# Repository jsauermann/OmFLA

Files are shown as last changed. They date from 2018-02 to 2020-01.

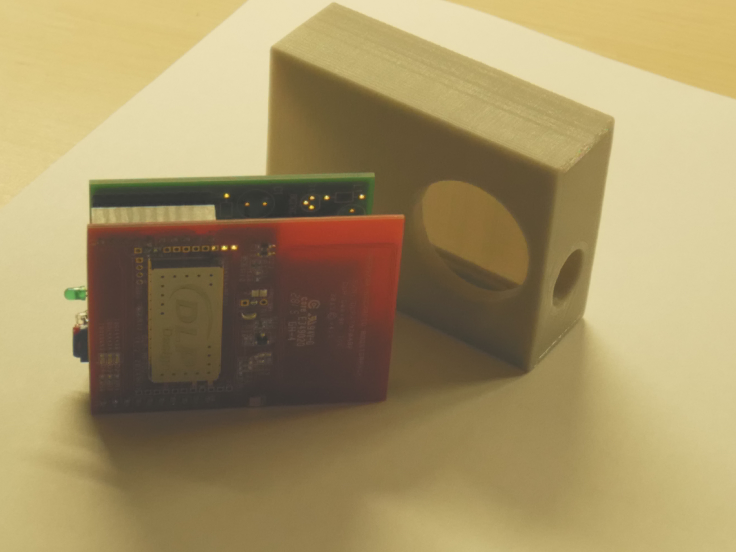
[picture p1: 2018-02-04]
pictures/components.jpg

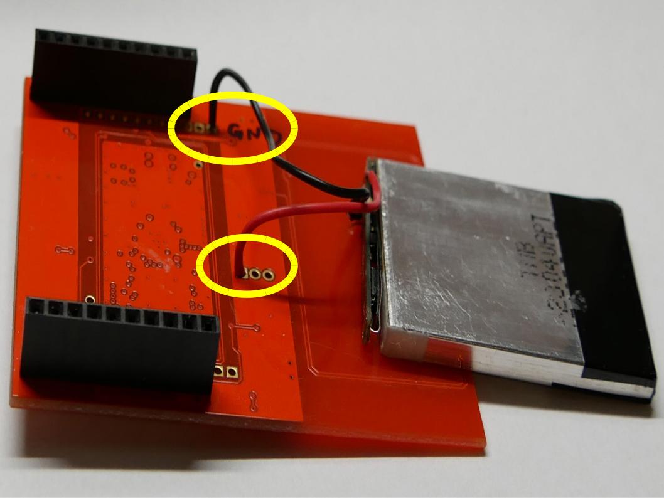
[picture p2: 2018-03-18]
hardware/battery_connected.jpg

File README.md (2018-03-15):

# OmFLA
**O**ne **m**ore **F**reestyle **L**ibre **A**larm

This project contains the hardware (schematic and PCB layout), micro-controller
software (C++ for an Atmel ATtiny 4313), and mechanics (openscad file for 3D
printers) of a small device that MAY be useful for users of Freestyle Libre
glucose sensors. The device beeps if the glucose levels reported by the
sensors exceed certain thresholds.

The device is only reading the sensors and can therefore co-exist with the
standard reader shipped by Abbott. As a consequence the device cannot
initialize new sensors. The primary purpose of the device is to be worn at
night and to warn the user about excessive glucose levels. The purpose is
NOT to replace the standard Abbott reader. In fact, the first action after
an alarm shall be to determine the glucose level with either the standard
reader, or even with a traditional blood glucose measurement.

The PCB of the device is prepared for an Enocean TCM 310 module that can
transmit the glucose levels and the battery level to a receiver withing,
say, 20 meters. Low-cost receiver modules, for example for Raspberry Pis
are available. Alternatively, one can used a second OmFLA PCB as receiver
and connect it to the serial port of a Raspberry Pi or of some
micro-controller.

**DISCLAIMER: This device is not a medical device and does not follow
any established standards for medical devices. It is a purely experimental
device and only meant to demonstrate technical possibilities.**

**The information in this project is distributed in the hope that it will be
useful, but WITHOUT ANY WARRANTY; without even the implied warranty of
MERCHANTABILITY or FITNESS FOR A PARTICULAR PURPOSE.**

A distinguishing feature of the device described in this project is that
it works without any additional devices like expensive smart watches or even
smart-phones. One of the design goals was low cost as opposed to high
functionality, and the cost of the components for the prototype were well
below US-$ 50.00 (including the RFID reader, but excluding the PCB and the
optional TCM 310 radio transceiver).

We are offering OmFLA PCBs to diabetes self aid groups and to individuals suffering
from diabetes at roughly our purchase price + shipping, please send an email to
**omfla@jürgen-sauermann.de** for details.

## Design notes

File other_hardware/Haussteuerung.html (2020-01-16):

Table of Contents

## Jürgen’s Raspberry Pi Zero hat

### Overview

Unlike other Raspberry hats, this hat is larger than the Raspberry Zero, so the raspberry is plugged onto the hat rather than the hat being plugged onto the rapberry.

Although the hat was designed for the Raspberry Pi Zero form factor, it supposedly also works for other Raspberry Pi models.

The hat contains only a few active components; the rest is connectors for various purposes. Almost all components are optional and only needed if the interface that they belong to is needed. The hat provides the following connectors/interfaces:

- J1: The main interface between the hat and the Raspberry Pi Zero
- X1: an interface to a 3 Line LCD Display
- J2: an interface for enocean TCM310 hat (or alternatively a serial interface at 3.3 Volt level (!))
- J3, J4, J5 and J6: I²C interfaces (on the same I²C bus)
- J11/J12 open-collector outputs connected to the Raspi’s hardware PWM units
- J9 and J10: two 220Volt Relays
- SW1: one pushbutton
- J8: 20 pin header with some more general purpose interface lines

All these interfaces are controlled via GPIO lines of the Raspberry; the I²C and PWM interfaces can be realized either in software or in hardware.

### The main connector J1

The only non-optional component is J1, which connects the hat with a Raspberry Pi Zero. The hat gets its power (3.3 and 5 Volts) via its J1 from the Raspberry, therefore the power from the power supply should go into the Raspberry’s normal power connector (J1/PWR IN), and not to the hat’s J1.

Most of the remaining lines on J1 are GPIO lines. Unfortunately there exist exist 2 different naming/numbering conventions: the Broadcom scheme and the WiringPi scheme. If you control the GIPO pins by reading from and writing to files below /sys/class/gpio then the GPIO numbers used are those defined by the Broadcom scheme. If you instead use a library like wiringPi, then the pin numbers are completely differen and are defined by the WiringPi scheme. The following table shows the mapping between the pin numbers of the hat’s J1 connector, the Broadcom scheme, and the WiringPi scheme:

Alias | Wiring Pi Name | Broadcom Name | J1 Pin | | Broadcom Name | Wiring Pi Name | Alias
Power 3.3 Volts | | | 1 | 2 | Power 5 Volts
I²C Data | GPIO-8 | GPIO-2 | 3 | 4
I²C Clock | GPIO-9 | GPIO-3 | 5 | 6 | GND
| GPIO-7 | GPIO-4 | 7 | 8 | GPIO-14 | GPIO-15
GND | | | 9 | 10 | GPIO-15 | GPIO-16
| GPIO-0 | GPIO-17 | 11 | 12 | GPIO-18 | GPIO-1
| GPIO-2 | GPIO-27 | 13 | 14 | GND
| GPIO-3 | GPIO-22 | 15 | 16 | GPIO-23 | GPIO-4
Power | | | 17 | 18 | GPIO-24 | GPIO-5
| GPIO-12 | GPIO-10 | 19 | 20 | GND
| GPIO-13 | GPIO-9 | 21 | 22 | GPIO-25 | GPIO-6
| GPIO-14 | GPIO-11 | 23 | 24 | GPIO-8 | GPIO-10
GND | | | 25 | 26 | GPIO-7 | GPIO-11
| GPIO-30 | | 27 | 28 | GPIO-1 | GPIO-31
| GPIO-21 | GPIO-5 | 29 | 30 | GND
| GPIO-22 | GPIO-6 | 31 | 32 | GPIO-12 | GPIO-26 | PWM-0
PWM-1 | GPIO-23 | GPIO-13 | 33 | 34 | GND
| GPIO-24 | GPIO-19 | 35 | 36 | GPIO-16 | GPIO-27
| GPIO-25 | GPIO-26 | 37 | 38 | GPIO-20 | GPIO-28
GND | | | 39 | 40 | GPIO-21 | GPIO-29

### Enocean connector J2

J2 connects the hat with an Enocean TCM310 based Raspi Transceiver Module. The enocean Module is plugged directly onto J2 of the hat. The connection uses the RxD and TxD lines of RasPi UART (aka. /dev/ttyAMA0). The Data format is 57600 Baud, 8N1. Instead of the TCM310 Module, you can use this connector for other purposes that need a serial connection.

The Enocean connector J2 has the following pinout:

Alias | J2 Pin | | Broadcom Name | Wiring Pi Name | Alias
Power 3.3 Volts | 1 | 2 | -
- | 3 | 4 | -
- | 5 | 6 | GND
- | 7 | 8 | GPIO-14 | GPIO-15 | RxD
- | 9 | 10 | GPIO-15 | GPIO-16 | TxD
- | 11 | 12 | -
- | 13 | 14 | -
- | 15 | 16 | -
- | 17 | 18 | -
- | 19 | 20 | -
- | 21 | 22 | -
- | 23 | 24 | -
- | 25 | 26 | -

### I²C connectors J3, J4, J5, and J6

These connectors are connected in parallel (so that they belong to the same I²C bus). They are typically used to connect sensors. It is normally better to put sensors that are located close to each other on one cable (bus connection) than using separate cables (star connection), because that way the signal reflections at the ends of (unterminated) cables are being reduced.

If the cable(s) are too long then the I²C becomes unreliable and buffering and/or proper termination of the cables might be needed. Another solution for long cables could be to run the I²C in software (using /sys/class/gpio/gpio9/value for the I²C clock and /sys/class/gpio/gpio8/value for the I²C data, instead of /dev/i2c-1.

Every I²C connector J3, J4, J5, or J6 has the same pinout:

Pin | Broadcom Name | WiringPi Name | Alias
1 | Power 3.3 Volts
2 | GPIO-2 | GPIO-8 | I²C Data
3 | GND
4 | GPIO-3 | GPIO-9 | I²C Clock

### LCD Display X1

The hat may optionally be equipped with a 3-line LCD Dispay. The display is mounted on connector X1, which is a standard 40-pin, 600 mil socket with some pins not used. The pinout of X1 is:

Alias | Wiring Pi Name | Broadcom Name | J1 Pin | | Broadcom Name | Wiring Pi Name | Alias
A1 + | J7 Pin 2 3.3/5 Volts | | 1 | 40 | GPIO-11 | GPIO-14 | RESET
C1 - | RLED | | 2 | 39 | GPIO-21 | GPIO-29 | RS
- | | | - | 38 | GND | | CSB
- | | | - | 37 | GPIO-20 | GPIO-28 | R/W
- | | | - | 36 | GPIO-16 | GPIO-27 | E
- | | | - | 35 | | 3.3 Volts | D0
- | | | - | 34 | | | D1
- | | | - | 33 | | | D2
- | | | - | 32 | | | D3
- | | | - | 31 | GPIO-7 | GPIO-11 | D4
- | | | - | 30 | GPIO-8 | GPIO-10 | D5
- | | | - | 29 | GPIO-25 | GPIO-6 | D6
- | | | - | 28 | GPIO-24 | GPIO-5 | D7
- | | | - | 27 | GND | | VSS
- | | | - | 26 | 3.3 Volts | | VDD
- | | | - | 25 | 3.3 Volts | | Vin
- | | | - | 24 | (charge pump) | | Vout
- | | | - | 23 | 3.3 Volts | | PSB
C2 - | GND | | 19 | 22 | (charge pump) | | CAP1P
A2 + | RLED | | 20 | 21 | (charge pump) | | CAP1N

### Backlight Power Selector J7

The optional LCD display X1 can by equipped with an optional LED backlight in order to improve its readability. The optional LED backlight can either be driven from 3.3 Volts or from 5 Volts. Driving it from 5 Volts is supposedly better since the current of the backlight (about 40 mA) does not flow through the RasPi’s 5Volt → 3.3Volt converter.

Jumper J7
1-2 | Run LED backlight from 3.3 Volts
2-3 | Run LED backlight from 5 Volts

Caution | The LED backlight current MUST be limited, this is accomplished by resistor below the LCD display X1. The PCB shows a value of 10 (Ohms). This value is, however, dependant on two factors: the setting of J7 and the color of the LEDs. Typical values lie between about 0 and 30 Ohms, if unsure start with 30 Ohms and decrease as needed. For prototyping use a connector instead of soldering a (possibly incorrect) resistor.

### Extension connector J8

Most of the GPIO lines that are not connected with specific interfaces are conncted to J8. That way additional components can be connected to the RasPi as needed. The Pinout of J8 is:

Wiring Pi Name | Broadcom Name | J8 Pins | | Broadcom Name | Wiring Pi Name
GPIO-13 | GPIO-9 | 1 | 2 | GPIO-10 | GPIO-12
GPIO-5 | GPIO-21 | 3 | 4 | GPIO-3 | GPIO-22
GPIO-6 | GPIO-22 | 5 | 6 | GPIO-4 | GPIO-23
GPIO-19 | GPIO-24 | 7 | 8 | Power 3.3V
GND | | 9 | 10 | GPIO-25 | GPIO-26

### 220 Volt Connectors J9 and J10

The hat can be equipped with one or two relays that both can switch a 220 Volt power line. The Line (L) inputs of J9 and J10 are connected, it is therefore NOT possible to switch different phases, e.g. L1 and L2, of the same neutral (N) line.

The coils of each relays also operate at 220 Volt (or whatever voltage you choose for the relay components) and are galvanically isolated from the hat and the RasPi by means of optocoupler triacs (MOC 3041 or similar). The relay coild both use the primary AC input, therefore the secondary relay cannot be used without the primary.

Note | For operation at 110 Volts you may need smaller values for the 470 Ohm resistors above the LCD display X1. Refer to the MOC 3063 data sheet for details. The coils of the relays should be protected with varistors R7 resp. R8 that suppress inductive spikes when a coil is being turned off. The values of the varistors need to match the voltage used for the relay, e.g. 270 Volts for 220 Volt relay coils and 140 Volts for 110 Volt relay coils.

Warning | Unlike the coils of the relays, the relay contacts are NOT protected with varistors. For ohmic loads (e.g lamps) such protection is not needed, but for inductive loads (e.g. motors for blinds, door openers, etc.) additional protection for the relay contacts is recommended.

Connector J9, the primary 220 Volt connector, has one more pin than J10: this pin provides the neutral (N) line for both relay coils and contacts. The pinouts of J9 and J10 are:

J9 Pin | Purpose
1 | Line out if Relay-1 is ON
2 | Neutral (N)
3 | Line in (L)

J10 Pin | Purpose
1 | Line out if Relay-2 is OFF
2 | Line out if Relay-1 is OFF
3 | Line out if Relay-2 is ON

The relays (ON/OFF) are controlled with the following GPIO pins:

Broadcom Name | Wiring Pi Name | Relay
GPIO-17 | GPIO-0 | Relay-1 ON/OFF
GPIO-27 | GPIO-2 | Relay-2 ON/OFF

### PWM Connectors J11 and J12

J11 provides two PWM channels that are driven by the open collectors of the two transistors next to J1. These signals can be used, for example, to control the speed of fans. J11 has the following pinout:

J10 Pin | Broadcom Name | Wiring Pi Name | Alias
1 | GPIO-12 | GPIO-26 | PWM-1
2 | -
3 | GPIO-23 | GPIO-13 | PWM-0
4 | -
5 | GND

J11 is intended for the case where both PWM channels are routed over the same cable. In contrast, J12 is intended for the case where differen cables are used for the two PWM channels. J12 has the following pinout:

J10 Pin | Broadcom Name | Wiring Pi Name | Alias
1 | -
2 | -
3 | GPIO-12 | GPIO-26 | PWM-1
4 | -
5 | GND

If J12 is used, then typically pin 1 of J11 is not.

Last updated 2020-01-16 21:53:17 CET

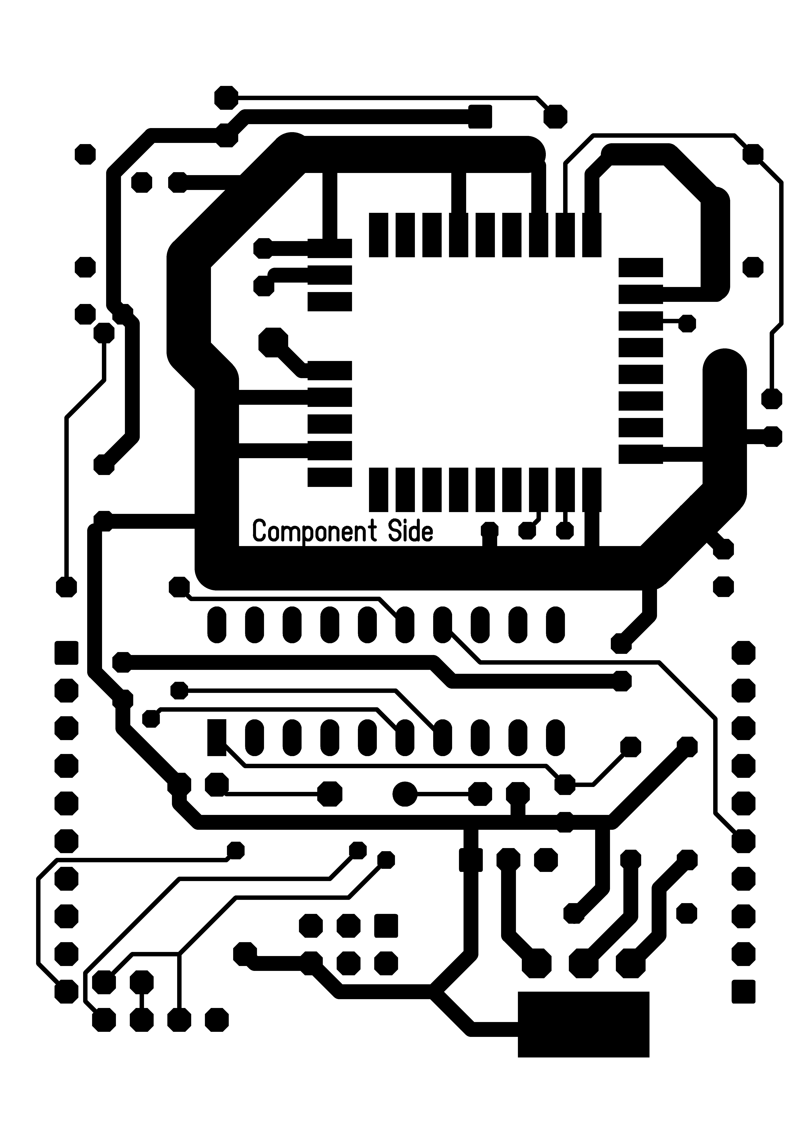
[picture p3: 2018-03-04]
hardware/Top.jpg

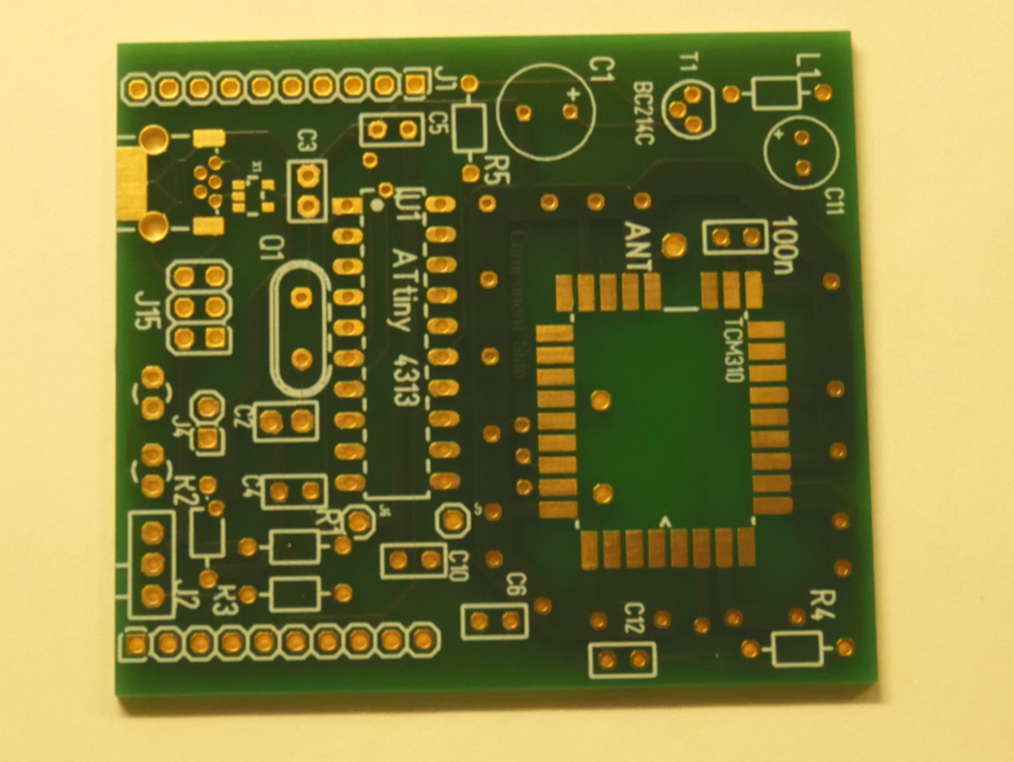
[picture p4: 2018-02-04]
hardware/PCB.jpg

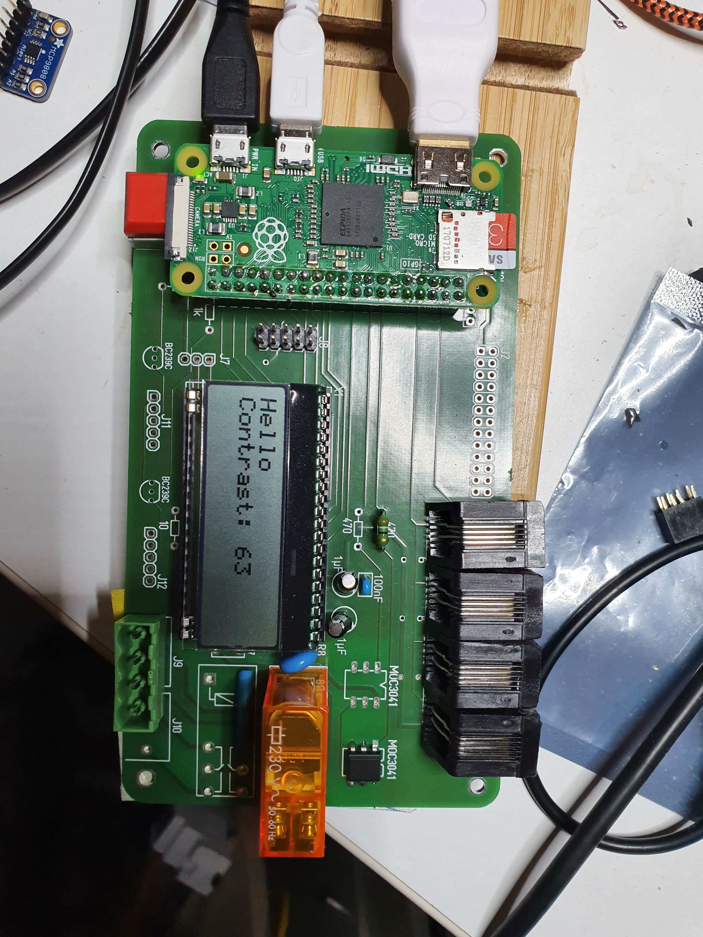
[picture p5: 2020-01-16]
other_hardware/Haussteuerung.jpg

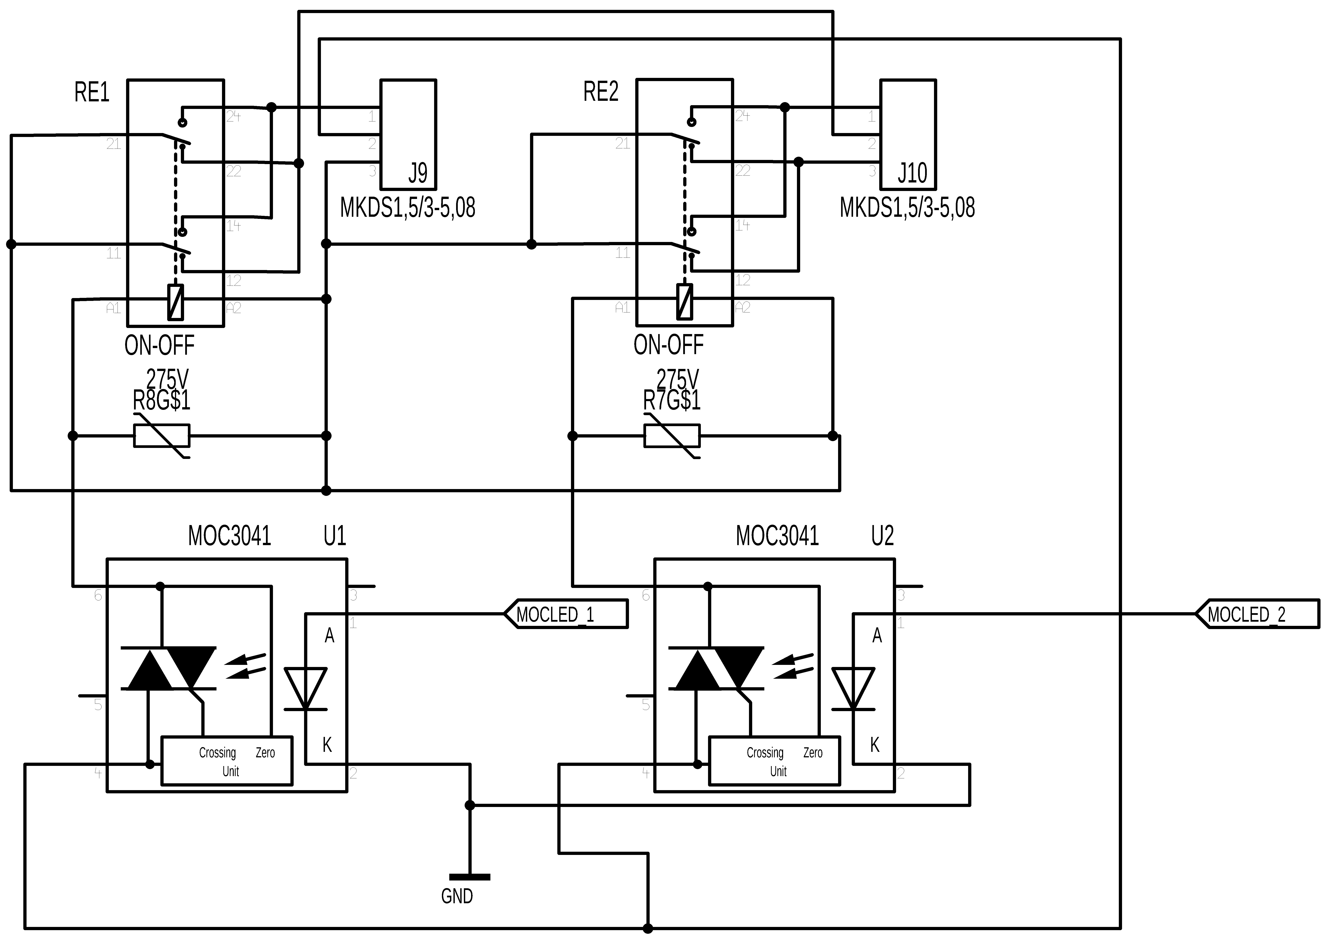
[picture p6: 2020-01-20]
other_hardware/Schematics_2.jpg

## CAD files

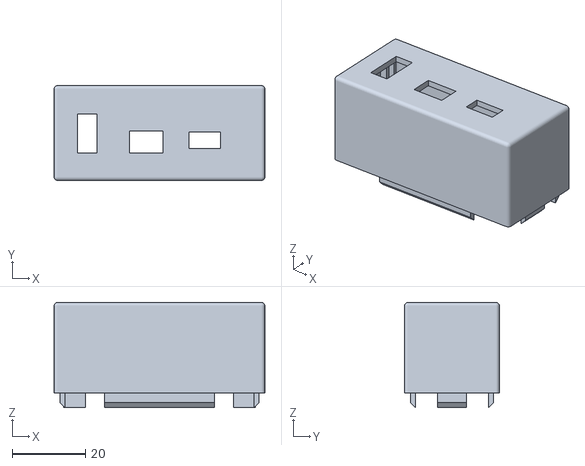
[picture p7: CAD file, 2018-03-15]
mechanics/alarm_upper.stl
57.6 x 25.9 x 28.7

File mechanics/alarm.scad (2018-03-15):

// variables that may be changed by the user
DEBUG  = 0;   // debug mode
UPPER  = 1;   // print the upper or lower half of the box
BUCKLE = 1;   // print the body with left and right belt loops
LEDS   = 1;   // do an LED cutout

// variables that ahould not be changed by the user

tb_cut_z = 50;

/// colors
c_green = [0, 1, 0];
c_red   = [1, 0, 0];

tolerance = 0.20;
tolerance2 = 2*tolerance;
tolerance4 = 4*tolerance;

sensor_radius = 15.5;

beeper_radius = 7.4;
beeper_trans = [21.5, 16.9, -14];

antenna_radius = 1.5;
antenna_trans = [42, 16.9, -14];

green_pcb_l  = 61.0;    // green PCB length
green_pcb_w  = 54.0;    // green PCB width
green_pcb_h  = 1.6;     // green PCB thickness
green_offset = 4.0;

red_pcb_l    = 66.5;           // red PCB length
red_pcb_w    = green_pcb_w;    // red PCB width
red_pcb_h    = 1.55;           // red PCB thickness
red_offset   = 6.0;

pcb_dist0    = 11.2;     // inner distance between green PCB and red PCB
pcb_dist     = pcb_dist0 + red_pcb_h;

box_thickness = 1.6;

box_y_red   = red_offset;               // red PCB position
box_y_green = box_y_red + pcb_dist;     // green PCB position
box_h_i = box_y_green + green_offset;
box_h_o = box_h_i + 2*box_thickness;

box_w_i = green_pcb_w + tolerance2;   // inner box width
box_w_o = box_w_i + 2*box_thickness;  // outer box width
box_l_i = red_pcb_l + 5;              // inner box length
box_l_o = box_l_i + 2*box_thickness;  // outer box length

pcb_guard_h = 1;
pcb_guard_w = box_thickness + 2;

pcb_guard_x1 = box_w_i + box_thickness - pcb_guard_w;
pcb_guard_x2 = pcb_guard_x1 + 1;

pcb_guard_y1 = box_y_red - pcb_guard_h;
pcb_guard_y2 = box_y_red + red_pcb_h + tolerance2;
pcb_guard_y3 = box_y_green - pcb_guard_h;
pcb_guard_y4 = box_y_green + green_pcb_h + tolerance2;

// the wide flap that connects the upper and lower halves of the box
//
flap_w = 8;
flap_h = 1.4;
flap1_l = 30;
flap2_l =  8;
flap3_l =  6;

module flap_2D(mirror)
{
flap_w2 = 0.5*flap_w;
flap_w2h = flap_w2 - flap_h;

   if (mirror)
      polygon([[-flap_w2,  0],
               [-flap_w2,  flap_h],
               [ flap_w2h, flap_h],
               [ flap_w2,  0]]);
   else
      polygon([[-flap_w2,  0],
               [-flap_w2,  flap_h],
               [ flap_w2,  flap_h],
               [ flap_w2h, 0]]);
}
module flap1(mirror)
{
   rotate([0, 90, 0])
   linear_extrude(height = flap1_l,
                  center = false,
                  convexity = 10,
                  twist = 0)   flap_2D(mirror);
}

// the narrow flap that connects the upper and lower halves of the box
//
module flap2(mirror)
{
   rotate([0, 90, 90])
   linear_extrude(height = flap2_l,
                  center = false,
                  convexity = 10,
                  twist = 0)   flap_2D(mirror);
}

module flap3(mirror)
{
   rotate([0, 90, 0])
   linear_extrude(height = flap3_l,
                  center = false,
                  convexity = 10,
                  twist = 0)   flap_2D(mirror);
}

// green PCB incl. tolerance
//
module
green_PCB()
{
   cube([
          green_pcb_w + tolerance2,
          green_pcb_h + tolerance2,
          green_pcb_l
        ]);
}

// red PCB incl. tolerance
//
module
red_PCB()
{
      cube([
             red_pcb_w + tolerance2,
             red_pcb_h + tolerance2,
             red_pcb_l
           ]);

      translate([10, red_pcb_h - 5, 0])
         cube([
                red_pcb_w - 20 + tolerance2,
                5,
                red_pcb_l
              ]);
}

module pcb_guard()
{
   square([pcb_guard_w, pcb_guard_h]);
}

module rounded_rect(w, h, r)
{
   translate([r,r])
   minkowski($fn=50)
      {
         square([w - 2*r, h - 2*r]);
         circle(r);
      }
}

module
profile_2D()
{
   difference()
      {
        square([box_w_o, box_h_o]);
        translate([box_thickness, box_thickness, 0])
           rounded_rect(box_w_i, box_h_i, 1);
      }

   translate([0, pcb_guard_y1, 0])   pcb_guard();
   translate([0, pcb_guard_y2, 0])   pcb_guard();
   translate([0, pcb_guard_y3, 0])   pcb_guard();
   translate([0, pcb_guard_y4, 0])   pcb_guard();

   translate([pcb_guard_x1, pcb_guard_y1, 0])   pcb_guard();
   translate([pcb_guard_x1, pcb_guard_y2, 0])   pcb_guard();
   translate([pcb_guard_x2, pcb_guard_y3, 0])   pcb_guard();
   translate([pcb_guard_x2, pcb_guard_y4, 0])   pcb_guard();
}

module profile_3D()
{
   linear_extrude(height = box_l_i,
                  center = false,
                  convexity = 10,
                  twist = 0) profile_2D();
}

/// the bottom, left, right, front, and back of the box.
/// the top (cover) of the box is printed separately.
module box_3D()
{
   // bottom plate
   //
   cube([box_w_o, box_h_o, box_thickness]);

   // 1mm thick ring around the beeper in the bottom plate
   //
   translate(beeper_trans)    cylinder(h = 17, r = beeper_radius + 1, $fn = 90);

   // main body
   //
   translate([0, 0, box_thickness])   profile_3D();


   if (DEBUG)
      {
        color(c_green)
        translate([box_thickness, box_y_green, box_thickness])
        green_PCB();

        color(c_red)
        translate([box_thickness, box_y_red, box_thickness])
        red_PCB();
      }

   // ring around the sensor in the main body
   //
   translate([box_w_o/2, 0, 20])
   rotate([-90, 0, 0])
   cylinder(h = 5, r = sensor_radius + 1, $fn = 90);

   // top plate
   //
   translate([0, 0, box_thickness + box_l_i])
      cube([box_w_o, box_h_o, box_thickness]);
}

/// the box with cutouts for the sensor and the beeper
module box_3D_cutout()
{
   difference()
      {
        box_3D();
        union()
           {
             // after rotate(-90, 0, 0)) below, in the standard view:
             //
             // x: left-right
             // y: front-back
             // z: up-down

             // sensor cutout
             //
             translate([box_w_o/2, 0, 20])
             rotate([-90, 0, 0])
             cylinder(h = 6, r = sensor_radius, $fn = 90);

             // beeper cutout
             //
             translate(beeper_trans)
             cylinder(h = 20, r = beeper_radius, $fn = 90);

             // antenna cutout
             //
             translate(antenna_trans)
             cylinder(h = 20, r = antenna_radius, $fn = 90);

             translate([0, 0.5*box_h_o, box_l_o - 5])
    //       mirror([0, 1, 0])
             translate([0, -0.5*box_h_o, 0])
             cover_3D_cutout();
           }
      }
}

/// a cube with rounded edges (to be intersected with the box)
module rounded_block(r)
{
   translate([r,r,r])
   minkowski($fn=50)
      {
        cube([box_w_o - 2*r, box_h_o - 2*r, box_l_o - 2*r]);
        sphere(r);
      }
}

/// the box except its cover
module main_body()
{
   intersection()
      {
        box_3D_cutout();
        rounded_block(1);
      }
}

// the cover for the box before rounding its edges
module cover_3D()
{
   // base plate
   //
   cube([box_w_o, box_h_o, box_thickness]);

   // guard next to green PCB
   //
   translate([5, box_thickness, box_thickness])
      cube([box_w_o - 10, 2, 5]);

   // guard next to red PCB
   //
   translate([5, box_h_o - box_thickness - 2, box_thickness])
      cube([box_w_o - 10, 2, 5]);
}

module cover_2D_cutout()
{
tol = 0.5;   // a little more than needed
tol2 = 2*tol;

leds_w   = 4.3 + tol2;
leds_h   = 9.7 + tol2;

prog_w   = 8.1 + tol2;
prog_h   = 5.0 + tol2;

switch_w = 7.6 + tol2;
switch_h = 3.5 + tol2;

leds_wh   = [leds_w,   leds_h];
prog_wh   = [prog_w,   prog_h];
switch_wh = [switch_w, switch_h];

// distances from left green PCB edge
//
gpcb_leds   =  4.9;
gpcb_prog   = 19.1;
gpcb_switch = 35.3;
gpcb_outer  =  2.0;   // left green PCB edge to box hull

leds_x   = gpcb_leds   + gpcb_outer - tol;
prog_x   = gpcb_prog   + gpcb_outer - tol;
switch_x = gpcb_switch + gpcb_outer - tol;

leds_y   = box_y_green - 0.8 + tol;
prog_y   = box_y_green - 0.8 + tol;
switch_y = box_y_green - 2.0 + tol;

   // cutout for the LED block
   //
   if (LEDS)
      {
        translate([leds_x, box_h_o - leds_y])
        square(leds_wh, center = false);
      }

   // cutout for the program connector
   //
   translate([prog_x, box_h_o - prog_y])
      square(prog_wh, center = false);

   // cutout for the on-off switch
   //
   translate([switch_x, box_h_o - switch_y])
      square(switch_wh, center = false);
}

module cover_3D_cutout()
{
   linear_extrude(height = 20,
                  center = false,
                  convexity = 2,
                  twist = 0) cover_2D_cutout();
}

/// a buckle for holding the housing, e.g. by means of a tourniquet
module buckle_2D(rnd)
{
l  = 35;
h1 =  3;
dh = 0.5;
h2 = h1 + dh;
wi =  1.141*(rnd + dh);
   polygon([[ 0,  0],               [wi,  0],
            [wi + h1, h1],          [wi + h1 + l, h1],
            [wi + h1 + l + h1, 0],  [wi + h1 + l + h1 + wi,  0],
            [wi + h1 + l + h1 + wi - h2, h2],          [h2, h2]]);
}
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

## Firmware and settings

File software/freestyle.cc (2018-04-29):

/*
    Copyright (C) 2018  Dr. Jürgen Sauermann

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
    You should have received a copy of the GNU General Public License
    along with this program.  If not, see <http://www.gnu.org/licenses/>.
*/

/*
 top-level functions for the OmFLA device
 */

// NOTE: ATtiny 4313 Fuse settings:
//
// Extended Fuse: 0xFF (default)
// High Fuse:     0xDF (default)
// Low Fuse:      set in Makefile and passed as -D $(FUSEL)
//
#if   FUSEL == 0xED
# define MAY_CALIBRATE 0   // CPU calibration has no effect (external Xtal used)
#elif FUSEL == 0xE2
# define MAY_CALIBRATE 1   // CPU calibration is possible (RC Oscillator used)
#else
# error "Bad/Unsupported Low Fuse Setting (expecting 0x6D or 0x62)"
#endif

#define F_CPU      3686400
#define  CPU_CALIB 0x3B
#define BAUDRATE   57600

#include "user_defined_parameters.hh"

enum EEPROM_addresses
{
   USER_PARAMS     = 0,      // copy of user_params (14 bytes)
   SENSOR_Cache    = 0x20,   // blocks 3..14 of the sensor (8 byte per block)

   SENSOR_Cache_3  = SENSOR_Cache,          // block 3:  0x20
   SENSOR_Cache_4  = SENSOR_Cache_3  + 8,   // block 4:  0x28
   SENSOR_Cache_5  = SENSOR_Cache_4  + 8,   // block 5:  0x30
   SENSOR_Cache_6  = SENSOR_Cache_5  + 8,   // block 6:  0x38
   SENSOR_Cache_7  = SENSOR_Cache_6  + 8,   // block 7:  0x40
   SENSOR_Cache_8  = SENSOR_Cache_7  + 8,   // block 8:  0x48
   SENSOR_Cache_9  = SENSOR_Cache_8  + 8,   // block 9:  0x50
   SENSOR_Cache_10 = SENSOR_Cache_9  + 8,   // block 10: 0x58
   SENSOR_Cache_11 = SENSOR_Cache_10 + 8,   // block 11: 0x60
   SENSOR_Cache_12 = SENSOR_Cache_11 + 8,   // block 12: 0x68
   SENSOR_Cache_13 = SENSOR_Cache_12 + 8,   // block 13: 0x70
   SENSOR_Cache_14 = SENSOR_Cache_13 + 8,   // block 14: 0x78
   E_pass              = 0x80,
   E_aver_2            = 0x81,
   E_initial_glucose_2 = 0x82,
   E_alarm_LOW__2      = 0x83,
   E_alarm_HIGH__2     = 0x84,
   GLUCO_trend_idx     = 0x85,
   GLUCO_hist_idx      = 0x86,

   GLUCO_trend         = 0xD0,
   GLUCO_history       = 0xE0,
};

static uint16_t cache = 0;
#define F_IO  F_CPU

#include <avr/io.h>
#include <avr/eeprom.h>
#include <avr/interrupt.h>
#include <avr/pgmspace.h>
#include <avr/sleep.h>
#include <string.h>
#include <util/delay.h>

uint16_t pass = 0;

/*
 delta_LOW resp. delta_HIGH are additional margins for the lower resp. upper
 alarm thresholds. If the OmFLA device is started with a moderate glucose
 level, i.e. a glucose level between (alarm_LOW + margin_LOW) and
 (alarm_HIGH - margin_HIGH), then delta_LOW = delta_HIGH = 0 and remain 0.
 However, if the OmFLA device is started with a glucose level close to
 alarm_LOW resp. alarm_HIGH, then the lower resp, upper alarm thresholds,
 then delta_LOW resp. delta_HIGH are temporarily set to a value > 0 (to avoid
 false alarms) and are decreased until a moderate glucose level is reached.
*/
static int8_t delta_LOW__2  = 0;   // additional margin for the LOW alarm
static int8_t delta_HIGH__2 = 0;   // additional margin for the HIGH alarm

/// a 1:1 copy of the EEPROM data, initialized at startup
User_defined_parameters user_params;

#ifndef __AVR_ATtiny4313__
# error "__AVR_ATtiny4313__ is not defined !!!"
#endif

static void print_char(char ch);

static void enable_enocean();
static void disable_enocean();
static void transmit_glucose(uint8_t gluco_2);
static void transmit_change_bitmap();
static void transmit_changed_values();
static uint8_t crc = 0;
static uint8_t changed_bitmap[13];   // blocks 3-15 incl.
static uint8_t changed_values[10];
static uint8_t changed_idx = 0;

#define get_pin(port, bit)    (PIN  ## port &    port ## _ ## bit ? 0xFF : 0x00)
#define set_pin(port, bit)    (PORT ## port |=   port ## _ ## bit)
#define clr_pin(port, bit)    (PORT ## port &= ~ port ## _ ## bit)
#define output_pin(port, bit) (DDR  ## port |=   port ## _ ## bit)
#define input_pin(port, bit)  (DDR  ## port &= ~ port ## _ ## bit)

static void
write_cache(uint8_t value)
{
const uint8_t old = eeprom_read_byte((const uint8_t *)cache);
   if (old != value)   // value change
      {
        const uint8_t changed_addr = cache - SENSOR_Cache;
        const uint8_t changed_byte = changed_addr >> 3;
        const uint8_t changed_bit = changed_addr & 7;
        changed_bitmap[changed_byte] |= (0x80 >> changed_bit);
        if (changed_idx < sizeof(changed_values))
           changed_values[changed_idx++] = value;
        eeprom_write_byte((uint8_t *)cache, value);
      }

   ++cache;
}

enum IO_pins
{
   __A_XTAL_1  = 1 << PA0,   // XTAL1 (not used)
   __A_XTAL_2  = 1 << PA1,   // XTAL2 (not used)
   __A_RESET   = 1 << PA2,   // RESET (NEVER drive it  high!)
   outputs_A   = __A_XTAL_1
               | __A_XTAL_2,
   pullup_A  = 0,

   B_BTEST_OUT = 1 << PB0,     // battery test output
   B_BTEST_IN  = 1 << PB1,     // battery test input
   B_MOSI      = 1 << PB2,     // MOSI to RFID reader
   B_TCM_POWER = 1 << PB3,     // Power for TCM 310 radio module
   B_LED_GREEN = 1 << PB4,     // green LED
   B_PROG_MOSI = 1 << PB5,     // MOSI from serial programmer
   B_PROG_MISO = 1 << PB6,     // MISO to   serial programmer (not used)
   B_PROG_SCL  = 1 << PB7,     // SCL  from serial programmer
   B_RFID_EN   = B_PROG_SCL,   // active high RFID enable output
   B_JUMPER    = B_PROG_MOSI,  // beep mute jumper

   outputs_B   = B_BTEST_OUT
               | B_MOSI
               | B_TCM_POWER
               | B_LED_GREEN
               | B_PROG_MISO  // soft UART TxD
               | B_RFID_EN,
   pullup_B = B_JUMPER,

   D_TCM_RxD   = 1 << PD0,   // RxD from TCM 310 radio module
   D_TCM_TxD   = 1 << PD1,   // TxD to   TCM 310 radio module
   D_SCLK      = 1 << PD2,   // Data clock to RFID reader
   D_SSEL      = 1 << PD3,   // Slave SELect to RFID reader
   D_LED_RED   = 1 << PD4,   // red LED
   D_MISO      = 1 << PD5,   // MISO from RFID reader
   D_BEEPER    = 1 << PD6,   // beeper
   outputs_D   = D_TCM_TxD
               | D_SCLK
               | D_SSEL
               | D_LED_RED
               | D_BEEPER,
   pullup_D  = 0,
};

enum BOARD_STATUS
{
   BSTAT_RESET         = 0,
   BSTAT_RFID_ERROR    = 3,
   BSTAT_RUNNING       = 7,
   BSTAT_ABOVE_INITIAL = 6,
   BSTAT_BELOW_INITIAL = 4,
};

#include "UART.cc"

static uint8_t  board_status = BSTAT_RESET;
static uint8_t  trend_idx = 0;
static uint8_t  hist_idx = 0;

static uint16_t batt_result = 0;
static uint8_t  initial_glucose_2 = 0;

//-----------------------------------------------------------------------------
/// wait for \b milli_secs ms, return time slept (which can be less than
/// the time requested if \b milli_secs is too large)
static uint32_t
sleep_ms(uint32_t milli_secs)
{
   enum {
          // CTC frequencies after prescaler
          //
          PRE_1 = 1,   // prescaler: ÷1
          PRE_2 = 5,   // prescaler: ÷1024

          F_CTC_1   =  F_IO,          // 4 MHz,   Tmax = 16.384 msec
          F_CTC_2   =  F_IO / 1024,   // 3906 Hz, Tmax = 16.777 sec

          WGmode    = 4,              // alias CTC mode, p. 113
          WGmode_A  = (WGmode & 0x03) << WGM10,
          WGmode_B  = (WGmode >> 2)   << WGM12,
        };

   // timer in CRC mode with 20 ms interval
   //
   // WGM13..10 is 0100 p. 113, (split between TCCR1B and TCCR1A)
   TCCR1A = 0 << COM1A0   // normal mode, OC1A disconnected, see p. 111
          | 0 << COM1B0   // normal mode, OC1B disconnected, see p. 111
          | WGmode_A      // WGM11:WGM10 = 00  p. 111
          ;

   if (milli_secs < 16)   // short sleep
      {
        TCCR1B = WGmode_B        // WGM13:WGM12 = 01  p. 113
               | PRE_1 << CS10   // prescaler: io-clk
               ;

        //      (max. <  64,000,000)
        OCR1A = (F_CTC_1 * milli_secs) / 1000;
      }
   else
      {
        if (milli_secs > 16000)   // very long sleep
           {
             milli_secs = 16000;
           }

        TCCR1B = WGmode_B        // WGM13:WGM12 = 01  p. 113
               | PRE_2 << CS10   // prescaler: io-clk
               ;

        //      (max. <  64,000,000)
        OCR1A = (F_CTC_2 * milli_secs) / 1000;
      }

   TCNT1 = 0;
   TIFR  = 1 << OCIE1A;   // clear old interrupts
   TIMSK = 1 << OCIE1A;   // enable interrupts

   set_sleep_mode(SLEEP_MODE_IDLE);

   sleep_enable();
   sei();
   sleep_cpu();
   cli();
   sleep_disable();

   TIMSK = 0;             // disable timer interrupts
   return milli_secs;
}
//-----------------------------------------------------------------------------
#define MAX_FIFO 10
#include "RFID_functions.cc"

# include "enocean.cc"
//-----------------------------------------------------------------------------
static void
init_hardware()
{
   // set GPIO directions
   //
   DDRA = outputs_A;
   DDRB = outputs_B;
   DDRD = outputs_D;

   PORTA = pullup_A;
   PORTB = pullup_B | B_TCM_POWER;
   PORTD = pullup_D | D_BEEPER | D_SSEL;

   init_uart();

   // set analog comparator to inactive state

   ACSR = 1 << ACD     // DO     disable comparator
        | 0 << ACBG    // DO NOT use internal bandgap reference
        | 0 << ACI     // DO NOT clear interrupt
        | 0 << ACIE    // DO NOT enable interrupt
        | 0 << ACIC    // DO NOT enable input capture
        | 2 << ACIS0   // interrupt on falling edge
        ;

   DIDR = 1 << AIN0D    // disable AIN0 digital input
        | 1 << AIN1D;   // disable AIN1 digital input
}
//-----------------------------------------------------------------------------
ISR(TIMER1_COMPA_vect)
{
}
//-----------------------------------------------------------------------------
ISR(ANA_COMP_vect)
{
   batt_result = TCNT1;
}
//-----------------------------------------------------------------------------
static void
print0(uint8_t format)
{
   print_char(format);
}
//-----------------------------------------------------------------------------
static void
print1(uint8_t format, uint16_t value)
 {
   print_char(format);
   print_char(value >> 8);
   print_char(value);
 }
//-----------------------------------------------------------------------------
static void
print2(uint8_t format, uint16_t value1, uint16_t value2)
 {
   print1(format, value1);
   print_char(value2 >> 8);
   print_char(value2);
 }
//-----------------------------------------------------------------------------
inline void
beep(uint8_t repeat, uint16_t ms_on, uint8_t ms_off)
{
   if ((PINB & B_JUMPER) == 0)   return;

//  print1(1, ms_on);
   for (int j = 0; j < repeat; ++j)
      {
        clr_pin(D, BEEPER);
        sleep_ms(ms_on);
        set_pin(D, BEEPER);
        sleep_ms(ms_off);
      }
}
//-----------------------------------------------------------------------------
static uint8_t gluco2_vec[15];   // glucose values (divided by 2!)
static uint8_t gluco_idx = 0;

/// store glucose (in mg% ÷ 2) in gluco2_vec
static void
gluco2(uint8_t rx_offset)
{
const uint16_t h = rx_data[rx_offset + 3] & 0x0F;   // upper 4 bits
const uint16_t l = rx_data[rx_offset + 2];          // lower 8 bits
const uint32_t raw_sensor = h << 8 | l;           // total 12 bits
const uint16_t glucose = user_params.sensor_offset
                       + ((raw_sensor * user_params.sensor_slope) / 1000);

    print2(2, raw_sensor, glucose);

   gluco2_vec[gluco_idx++] = glucose >> 1;
}
//-----------------------------------------------------------------------------
/// sort gluco2_vec (15 items)
void
gluco_sort()
{
   for (uint8_t base = 0; base < (sizeof(gluco2_vec) - 1); ++base)
       {
          uint8_t smallest = base;
          for (uint8_t j = base + 1; j < sizeof(gluco2_vec); ++j)
              {
                if (gluco2_vec[j] < gluco2_vec[smallest])   smallest = j;
              }

         // exchange gluco2_vec[base] and gluco2_vec[smallest]
         //
         const uint8_t base_val = gluco2_vec[base];
         gluco2_vec[base] = gluco2_vec[smallest];
         gluco2_vec[smallest] = base_val;
       }
}
//-----------------------------------------------------------------------------
static bool
decode_Block(uint8_t block)
{
const uint8_t FIFO_len = read_register(FIFO_STATUS) & 0x7F;
   if (FIFO_len > MAX_FIFO)
      {
         print2(3, FIFO_len, __LINE__);
        goto error_out;
      }

   SPI_transfer(fifo, rx_data, FIFO_len + 1);

   // rx_data[0] is the leading SPI dummy, and
   // rx_data[1] is the ISO error code if != 0
   //
   if (FIFO_len == 2 || rx_data[1] != 0)   // ISO error code
      {
         print2(4, rx_data[1], __LINE__);
        goto error_out;
      }

   if (FIFO_len != 9)
      {
         print2(5, FIFO_len, __LINE__);
        goto error_out;
      }

   // the trend table is contained in blocks 4...15
   //
   if (block < 3)     return false;   // OK
   if (block >= 16)   return false;   // OK

    print2(6, block, 8*block);

   for (uint8_t j = 2; j <= 9; ++j)
       {
          write_cache(rx_data[j]);
           print1(7, rx_data[11 - j]);
       }

   if (block == 3)
      {
        hist_idx  = rx_data[5];
        trend_idx = rx_data[4];
         print2(8, trend_idx, hist_idx);
        return false;   // OK
      }

   // every ISO block contains 8 bytes resp. 4 16-bit measurements. There are 3
   // kinds of measurements, say aaaa, GGGG, and bbbb. The GGGG measurements are
   // raw glocose values while the nature of of measurements aaaa and bbbb is
   // currently unknown (one of them is probably a temperature value).
   //
   switch(block % 3)
      {
        case 0:            // 0011-2233-4455-6677
                 print0(9);
                gluco2(4); //           ^^^^
                break;

        case 1:            // 0011-2233-4455-6677
                 print0(10);
                gluco2(2); //      ^^^^
                break;

        case 2:            // 0011-2233-4455-6677
                 print0(11);
                gluco2(6); //                ^^^^
                gluco2(0); // ^^^^
                break;
      }

   return false;   // OK

error_out:
   beep(3, 200, 100);

   if ((block % 3) == 1)   gluco2_vec[gluco_idx++] = 0;   // 2 values per block
   gluco2_vec[gluco_idx++] = 0;                       // 1 more gluco2_vec
    print1(12, block);
   return true;   // error
}
//-----------------------------------------------------------------------------
uint8_t iso_read_block[8] =
   {
     CMD_reset_FIFO,
     CMD_send_with_CRC,
     CONT | TX_LENGTH_BYTE_1,   // write continuous from 1D
     0, 0x30,   // length (3)
     ISO_FLAGS, // ISO15693 flags
     0x20,      // ISO Read Single Block command code
     0,         // block number
   };

static bool
read_Block(uint8_t block)
{
   // at this point we expect: FIFO empty and interrupts off.
   //
   {
     const uint16_t len = read_register(FIFO_STATUS);
     if (len)
        {
           print2(13, len, __LINE__);
          Reset_FIFO();
        }

     if (const uint16_t stat = read_ISR())
        {
           print2(14, stat, __LINE__);
        }
   }

   iso_read_block[sizeof(iso_read_block) - 1] = block;
   SPI_transfer(iso_read_block, 0, sizeof(iso_read_block));

   sleep_ms(30);

const uint8_t istat = read_ISR();
   if ((istat & 0xC0) != 0xC0)
      {
         print1(15, istat);
         print1(16, block);
        return true;
      }

   return false;
}
//-----------------------------------------------------------------------------
inline void
dump_registers()
{
const uint8_t which[32] =   // do not read ISR status (0x0C) or FIFO (0x1F)
   { 0x00,  0x01,  0x02,  0x03,  0x04,  0x05,  0x06,  0x07,
     0x08,  0x09,  0x0A,  0x0B,  0xFF,  0x0D,  0x0E,  0x0F,
     0x10,  0x11,  0x12,  0x13,  0x14,  0x15,  0x16,  0x17,
     0x18,  0x19,  0x1A,  0x1B,  0x1C,  0x1D,  0x1E,  0xFF };

int values[32];

   // read registers...
   //
   for (uint8_t w = 0; w < sizeof(which); ++w)
       {
         const Register reg = (Register)(which[w]);
         if (reg != 0xFF)   values[w] = read_register(reg);
         else               values[w] = -1;
       }

   // print registers...
   //
    print0(17);

   for (uint8_t w = 0; w < sizeof(which); ++w)
       {
         if ((w & 7) == 0)    print1(18, w);
         if      (values[w] == -1)     print0(19);
         else if (values[w] == -2)     print0(20);
         else
            {
               print1(21, values[w]);
            }
       }

    print0(22);
}
//-----------------------------------------------------------------------------
void
LED_01(uint8_t val)
{
   enum { LED_ON = 600, LED_OFF = 200 };   // LED timing (ms)

   if (val & 1)   // 1: blink green LED
      {
        set_pin(B, LED_GREEN);    // green LED on
        sleep_ms(LED_ON);
        clr_pin(B, LED_GREEN);   // green LED off
      }
   else           // 0: blink red LED
      {
        set_pin(D, LED_RED);      // red LED on
        sleep_ms(LED_ON);
        clr_pin(D, LED_RED);     // red LED off
      }

   sleep_ms(LED_OFF);
}
//-----------------------------------------------------------------------------
void
battery_test()
{
   ACSR = 0 << ACD     // DO NOT disable comparator
        | 1 << ACBG    // DO     use internal bandgap reference
        | 0 << ACI     // DO NOT clear interrupt
        | 0 << ACIE    // DO NOT enable interrupt
        | 0 << ACIC    // DO NOT enable input capture
        | 2 << ACIS0   // interrupt on falling edge
        ;
   _delay_ms(1);       // wait 1 ms for bandgap reference to start up

   TCCR1A = 0;
   TCCR1B = 1 << CS10;       // clock source: io-clk

   batt_result = 9999;
   ACSR = 0 << ACD     // DO NOT disable comparator
        | 1 << ACBG    // DO     use internal bandgap reference
        | 1 << ACI     // DO     clear interrupt
        | 1 << ACIE    // DO     enable interrupt
        | 0 << ACIC    // DO NOT enable input capture
        | 2 << ACIS0   // interrupt on falling edge
        ;

   // make B_BTEST_OUT an input with pullup. The pullup then charges
   // capacitor C6.
   //
   input_pin(B, BTEST_OUT);  // BTEST_OUT: in: pullup charges capacitor
   set_pin(B, BTEST_OUT);    // enable pullup on AIN0

   TCNT1 = 0;
   sei();
   _delay_ms(1);          // DO NOT sleep_ms() !
   cli();

   ACSR = 1 << ACD     // DO     disable comparator
        | 0 << ACBG    // DO NOT use internal bandgap reference
        | 1 << ACI     // DO     clear interrupt
        | 0 << ACIE    // DO NOT enable interrupt
        | 0 << ACIC    // DO NOT enable input capture
        | 2 << ACIS0   // interrupt on falling edge
        ;

   // discharge capacitor for the next masurement
   //
   clr_pin(B, BTEST_OUT);      // disable pullup on AIN0
   output_pin(B, BTEST_OUT);   // BTEST_OUT direction = out
   clr_pin(B, BTEST_OUT);      // drive AIN0 low 
}
//-----------------------------------------------------------------------------
static void
set_delta_LOW__2(uint8_t glucose2)
{
const uint8_t limit2 = user_params.alarm_LOW__2 + user_params.margin_LOW__2;
   if (glucose2 >= limit2)   delta_LOW__2 = 0;
   else                      delta_LOW__2 = limit2 - glucose2;
}
//-----------------------------------------------------------------------------
static void
set_delta_HIGH__2(uint8_t glucose2)
{
const uint8_t limit2 = user_params.alarm_HIGH__2 - user_params.margin_HIGH__2;
   if (glucose2 <= limit2)   delta_HIGH__2 = 0;
   else                      delta_HIGH__2 = glucose2 - limit2;
}
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
int
main(int, char *[])
{
   // read user definable parameters from EEPROM
   {
     uint8_t * up = (uint8_t *)&user_params;
     for (uint16_t e = USER_PARAMS; e < sizeof(user_params); ++e)
         up[e] = eeprom_read_byte((const uint8_t *)e);
   }

   init_hardware();
   sleep_ms(50);

#if MAY_CALIBRATE
const uint8_t calib = user_params.oscillator_calibration;
   if (calib != 0xFF)   OSCCAL = calib;        // calibration override
   else                 OSCCAL = CPU_CALIB;
#endif

#if MAY_CALIBRATE
    print2(31, OSCCAL, CLKPR);
#else
    print1(32, CLKPR);
#endif
    print2(33, user_params.sensor_slope, user_params.sensor_offset);
    print2(34, user_params.alarm_HIGH__2  << 1, user_params.alarm_LOW__2   << 1);
    print2(35, user_params.margin_HIGH__2 << 1, user_params.margin_LOW__2  << 1);
    print2(36, user_params.battery_1__8 << 3, user_params.battery_2__8 << 3);
    print2(37, user_params.battery_3__8 << 3, user_params.battery_4__8 << 3);
    print1(38, user_params.battery_5__8 << 3);
    print2(39, user_params.read_error_retry__8 << 3, user_params.read_interval__8 << 3);

   // transmit a glucose value of 0 as a restart indication and to
   // inform receiver(s) about the battery status.
   //
   enable_enocean();
   transmit_glucose(0);

   for (pass = 0;; ++pass)
       {
//       dump_registers();
         int32_t wait = doit();
         while (wait > 0)   wait -= sleep_ms(wait);
       }
}
//-----------------------------------------------------------------------------

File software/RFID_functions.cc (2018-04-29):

/*
    Copyright (C) 2018  Dr. Jürgen Sauermann

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
    You should have received a copy of the GNU General Public License
    along with this program.  If not, see <http://www.gnu.org/licenses/>.
*/

/*
 functions for accessing a Texas Instruments TRF7970A via its SPI bus
 */

//-----------------------------------------------------------------------------
static void
SPI_transfer(const uint8_t * tx, uint8_t * rx, uint8_t length)
{
   // this function is called with SSEL=1, SCLK=0, and MOSI=0, and shall
   // return in the same state

   // start (assert nSSEL)
   //
   clr_pin(D, SSEL);

   for (uint8_t byte = 0; byte < length; ++byte)
       {
         const uint8_t vtx = tx[byte];
         uint8_t vrx = 0;
         for (uint8_t bit = 0x80; bit; bit >>= 1)
             {
               if (vtx & bit)   set_pin(B, MOSI);
               else             clr_pin(B, MOSI);
               set_pin(D, SCLK);                // ↑
               _delay_ms(0.1);
               vrx |= get_pin(D, MISO) & bit;   // sample Rx data
               clr_pin(D,SCLK);                 // ↓
               _delay_ms(0.2);
             }
         if (rx)   rx[byte] = vrx;
         _delay_ms(0.5);
       }

   // start (deassert SSEL)
   //
   clr_pin(B, MOSI);
   set_pin(D, SSEL);
   sleep_ms(1);
}
//-----------------------------------------------------------------------------
enum   // Table 6-20
{
   CONT              = 0x20,         // continuous address mode
   READ              = 0x40,         // read bit (0 for write)
   CMD               = 0x80,         // command bit (0 for parameters
   CMD_idle          = CMD | 0x00,   // direct command: idle
   CMD_init          = CMD | 0x03,   // direct command: init chip
   CMD_reset_FIFO    = CMD | 0x0F,   // direct command: reset FIFO
   CMD_send_with_CRC = CMD | 0x11,   // direct command: send and append CRC
};

enum Register
{
  CHIP_STATE_CONTROL       = 0x00,
  ISO_CONTROL              = 0x01,
  ISO_14443B_OPTIONS       = 0x02,
  ISO_14443A_OPTIONS       = 0x03,
  TX_TIMER_EPC_HIGH        = 0x04,
  TX_TIMER_EPC_LOW         = 0x05,
  TX_PULSE_LENGTH_CONTROL  = 0x06,
  RX_NO_RESPONSE_WAIT_TIME = 0x07,
  RX_WAIT_TIME             = 0x08,
  MODULATOR_CONTROL        = 0x09,
  RX_SPECIAL_SETTINGS      = 0x0A,
  REGULATOR_CONTROL        = 0x0B,
  IRQ_STATUS               = 0x0C,
  IRQ_MASK                 = 0x0D,   // Collision Pos and Interrupt Mask
  COLLISION_POSITION       = 0x0E,
  SPECIAL_FUNCTION         = 0x10,
  RAM_START_ADDRESS        = 0x11,   // RAM is 6 bytes long (0x11 - 0x16)
  ADJUSTABLE_FIFO_LEVEL    = 0x14,
  NFCID                    = 0x17,
  NFC_TARGET_LEVEL         = 0x18,
  TEST_SETTINGS_1          = 0x1A,
  TEST_SETTINGS_2          = 0x1B,
  FIFO_STATUS              = 0x1C,
  TX_LENGTH_BYTE_1         = 0x1D,
  TX_LENGTH_BYTE_2         = 0x1E,
  FIFO                     = 0x1F,
};

//-----------------------------------------------------------------------------
enum Register_value
{
   // register values
   //
   CHIP_VCC_3V       = 0x00,
   CHIP_VCC_5V       = 0x01,
   CHIP_VCC          = CHIP_VCC_3V,

   OUT_POWER_FULL    = 0x00,
   OUT_POWER_HALF    = 0x10,
   OUT_POWER         = OUT_POWER_HALF,

   CHIP_STATE_RF_Off = CHIP_VCC | OUT_POWER,
   CHIP_STATE_RF_On  = CHIP_STATE_RF_Off | 0x20,  // full power

   ISO_MODE_low      = 0x00,   // low bit rate, one subcarrier, 1(4)
   ISO_MODE_high     = 0x02,   // high bit rate, one subcarrier, 1(4)
   ISO_FLAGS_low     = 0x00,   // low data rate
   ISO_FLAGS_high    = 0x02,   // high data rate

   ISO_MODE = ISO_MODE_high,
   ISO_FLAGS = ISO_FLAGS_high,
};
//-----------------------------------------------------------------------------
const uint8_t fifo[1 + MAX_FIFO] = { READ | CONT | FIFO, 0 };
uint8_t rx_data[sizeof(fifo)];
//-----------------------------------------------------------------------------
static void
DirectCommand(uint8_t command)
{
   SPI_transfer(&command, 0, 1);
}
//-----------------------------------------------------------------------------
static void
Reset_FIFO()
{
   DirectCommand(CMD_reset_FIFO);
}
//-----------------------------------------------------------------------------
static uint8_t
read_register(Register reg)
{
uint8_t cmd[] = { uint8_t(READ | reg), uint8_t(READ | reg) };
   SPI_transfer(cmd, cmd, sizeof(cmd));
   return cmd[1];
}
//-----------------------------------------------------------------------------
static void
write_register(Register reg, uint8_t value)
{
uint8_t cmd[] = { reg, value };
   SPI_transfer(cmd, 0, sizeof(cmd));
}
//-----------------------------------------------------------------------------
inline void
init_RFID_reader()
{
   DirectCommand(CMD_init);
   DirectCommand(CMD_idle);

   Reset_FIFO();


   write_register(CHIP_STATE_CONTROL, CHIP_STATE_RF_Off);

   write_register(ISO_CONTROL, 0x00);

   write_register(NFC_TARGET_LEVEL, 0x00);   // fix TI bug
}
//-----------------------------------------------------------------------------
const uint8_t setup[] =
{
    CONT | CHIP_STATE_CONTROL,
    CHIP_STATE_RF_On,   // chip status:
    ISO_MODE,
    0x00,        // ISO_14443B_OPTIONS
    0x00,        // ISO_14443A_OPTIONS
    0xC1,        // TX_TIMER_EPC_HIGH
    0xBB,        // TX_TIMER_EPC_LOW
    0x00,        // TX_PULSE_LENGTH_CONTROL
    0x30,        // RX_NO_RESPONSE_WAIT_TIME
    0x1F,        // RX_WAIT_TIME
    0x01,        // MODULATOR_CONTROL
    0x40,        // RX_SPECIAL_SETTINGS = 424-kHz subcarrier for ISO 15693
    0x03,        // REGULATOR_CONTROL
};
//-----------------------------------------------------------------------------
inline void
setup_RFID_reader()
{
   set_pin(B, RFID_EN);
   sleep_ms(10);
   init_RFID_reader();

   SPI_transfer(setup, 0, sizeof(setup));
   sleep_ms(10);   // > 6 ms
}
//-----------------------------------------------------------------------------
static void
RF_Off()
{
   write_register(CHIP_STATE_CONTROL, CHIP_STATE_RF_Off);
}
//-----------------------------------------------------------------------------
static uint8_t
read_ISR()
{
uint8_t cmd[] = { uint8_t(READ | CONT | 0x0C),
                  uint8_t(READ | 0x0D),   // quirk
                  0 };
   SPI_transfer(cmd, cmd, sizeof(cmd));
   return cmd[1];
}
//-----------------------------------------------------------------------------

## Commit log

2018-02-04 initial check-in
    [alarm.scad]
2018-02-05 stl files added
    [alarm.scad, alarm.stl, alarm_cover.stl]
2018-02-05 PCB layout added
2018-02-05 README.Connector-J15 added
2018-02-19 buckles added
    [alarm.scad, alarm_with_buckle.stl, alarm_without_buckle.stl]
2018-02-19 replace alarm.stl by alarm_without_buckle.stl and alarm_with_buckle.stl variants
    [alarm.stl]
2018-02-20 simplified Schematics
2018-02-21 add audible battery level indication at power on
2018-02-26 remove snap-in flap
    [alarm.scad, alarm_cover.stl, alarm_with_buckle.stl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]
2018-02-26 add device usage description
2018-03-01 new casing that prints better
    [alarm.scad, alarm_cover.stl, alarm_lower_with_buckle.stl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]
2018-03-01 fixed displaced left flap
    [alarm.scad, alarm_upper.stl]
2018-03-04 Schematics for 2nd PCB series
2018-03-04 PCB v2
2018-03-15 adatpation to new PCB
    [alarm.scad, alarm_lower_with_buckle.stl, alarm_lower_without_buckle.stl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]
2018-03-18 fix On/Off switch direction
2018-03-28 improve CPU calibration and debug printouts
2018-03-30 store last sensor data in EEPROM
2018-04-04 change F_CPU to 3,686,400; move UART functions to UART.cc
2018-04-21 move all printf() format strings to OmFLA_printer.cc utility
2018-04-21 new compressed debug print mechanism
2018-05-28 add sensor table details
2020-01-16 PCB version 2
2020-01-20 add schematics

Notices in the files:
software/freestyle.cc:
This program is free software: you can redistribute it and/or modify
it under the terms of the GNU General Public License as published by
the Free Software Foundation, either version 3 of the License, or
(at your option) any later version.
